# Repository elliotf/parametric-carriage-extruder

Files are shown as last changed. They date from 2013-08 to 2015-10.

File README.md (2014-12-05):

A perimetric modular carriage + extruder system.

Heavily inspired by http://www.thingiverse.com/thing:321523

Currently designing for direct-driving 3mm filament.  Note that you'll likely want to use a 0.9 degree (400-step) motor to have sufficient steps/mm and/or 1/32 microstepping.

The design is parametric and should be able to be changed to 1.75mm filament if you so desire -- see 'filament_diam' variable.

The idea is that the extruder bolts to the face of the motor, then the motor is clamped to the x carriage in some way, assuming an XZ/Y printer.  Currently designing for a Graber/Prusa i3 vertical carriage, but a wades-style two-hole mounting system shouldn't be hard at all.

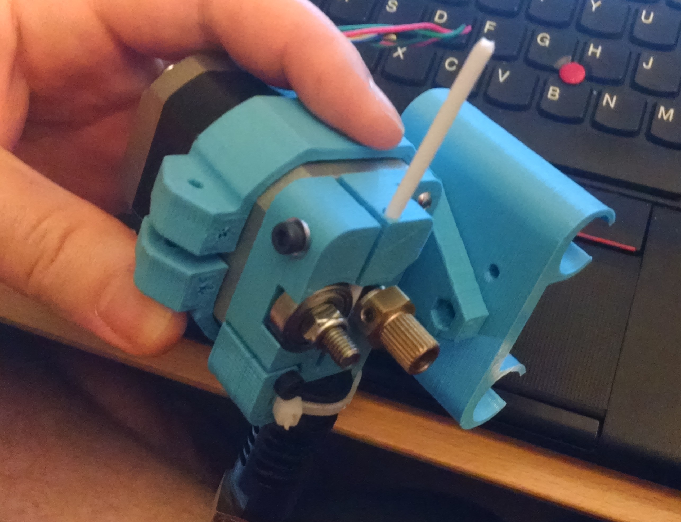
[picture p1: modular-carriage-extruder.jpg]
preview


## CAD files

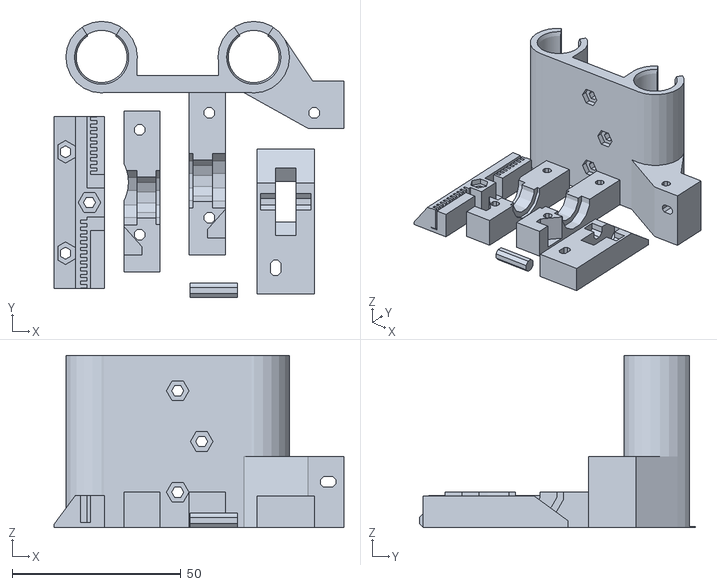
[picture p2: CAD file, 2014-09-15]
output/main_plate.stl
85.8 x 81.7 x 51.0

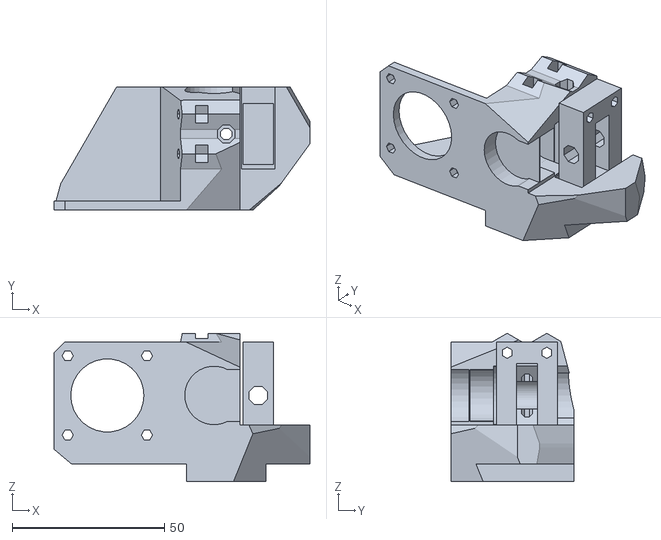
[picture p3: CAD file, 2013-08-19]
stl/assembly.stl
84.0 x 40.5 x 48.7

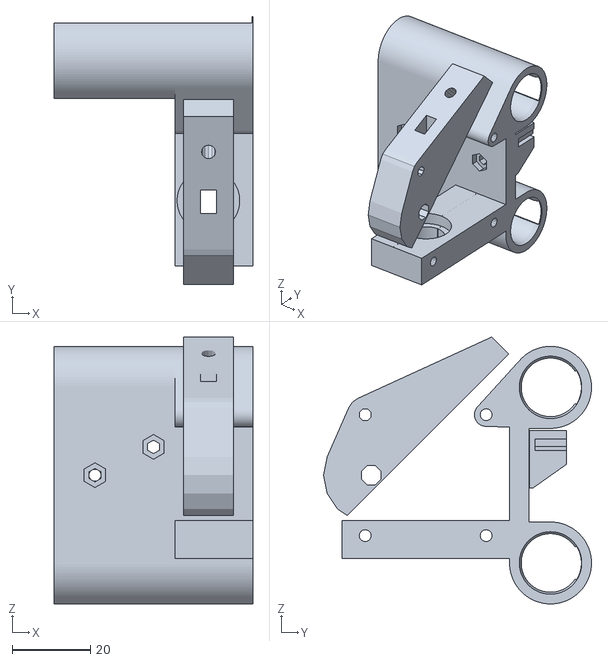
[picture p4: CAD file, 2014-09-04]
output/assembly.stl
51.0 x 68.7 x 68.4

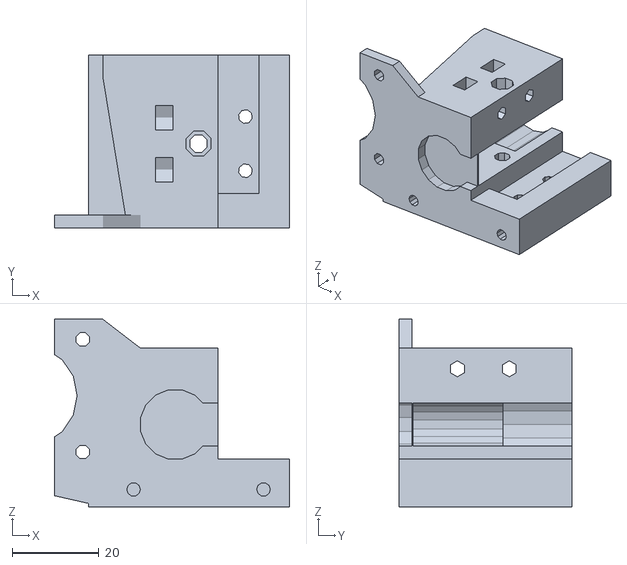
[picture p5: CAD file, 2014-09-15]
main.stl
54.3 x 40.0 x 43.3

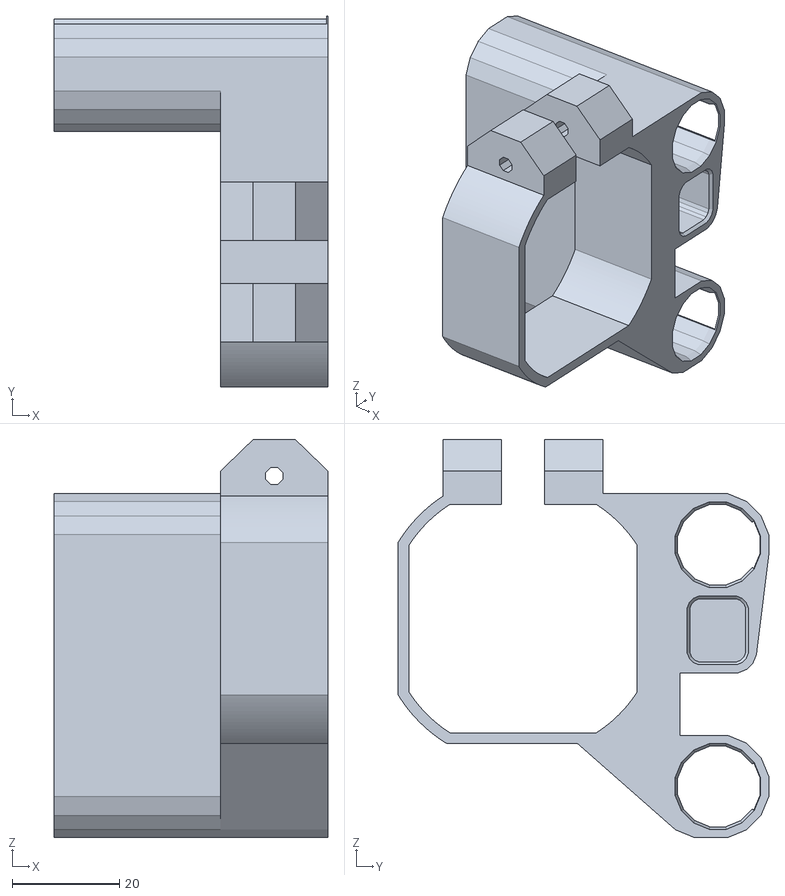
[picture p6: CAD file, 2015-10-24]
carriage-only.stl
51.0 x 69.0 x 74.1

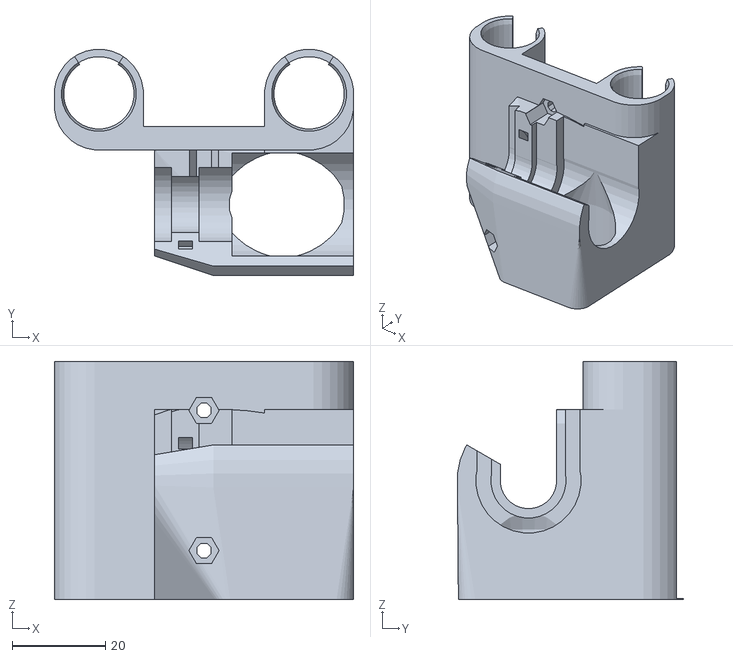
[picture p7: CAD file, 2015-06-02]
e3d-carriage-only.stl
64.0 x 48.4 x 51.0

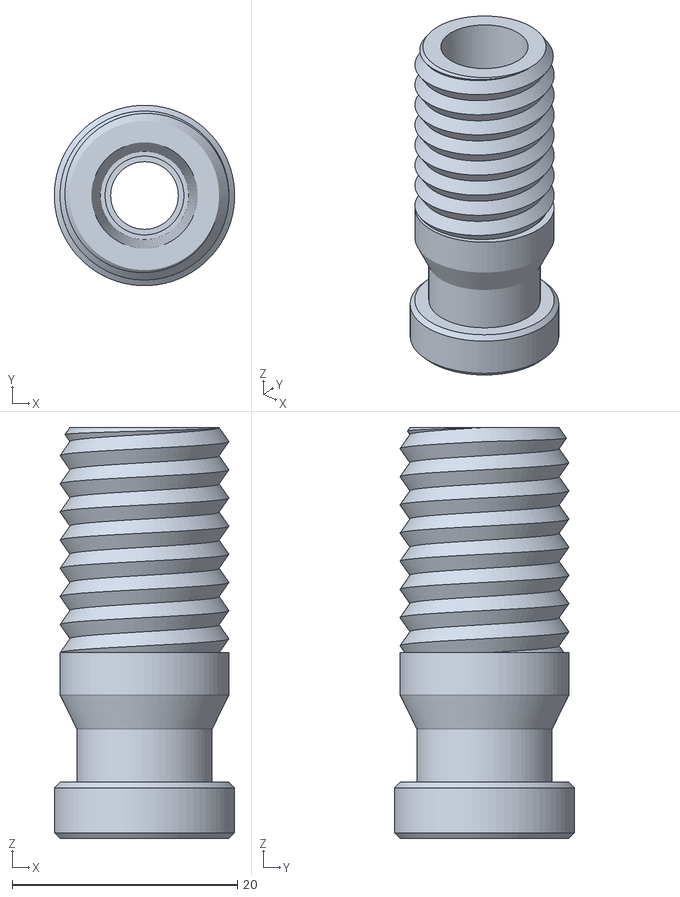
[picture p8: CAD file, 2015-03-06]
bowden-jhead-adapter.stl
16.0 x 16.0 x 36.5

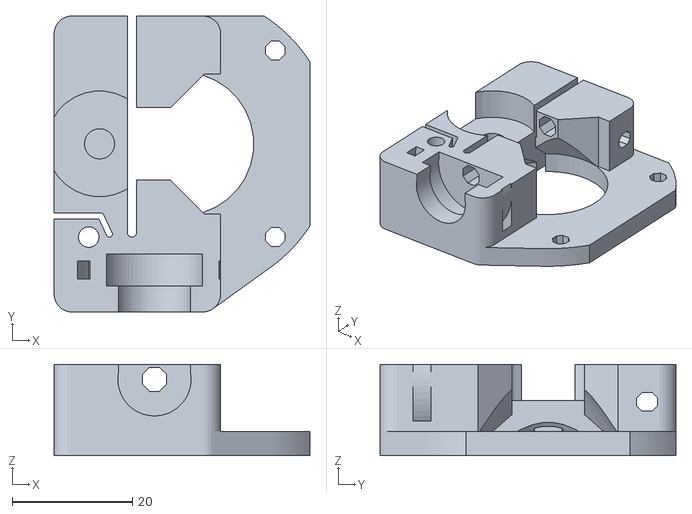
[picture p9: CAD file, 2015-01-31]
direct-drive-only.stl
42.5 x 49.2 x 15.2

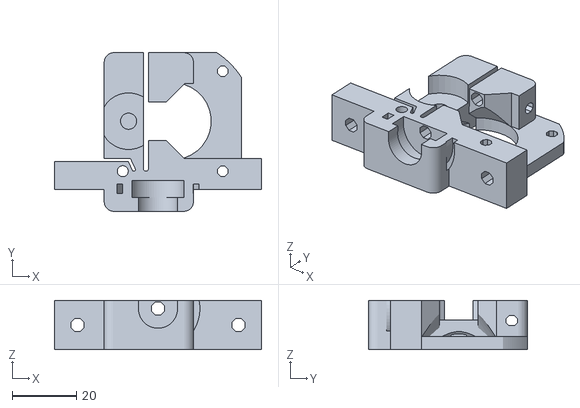
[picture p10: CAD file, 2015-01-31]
direct-drive-only-groove_mount_flush_with_motor-jhead.stl
64.2 x 49.2 x 15.2

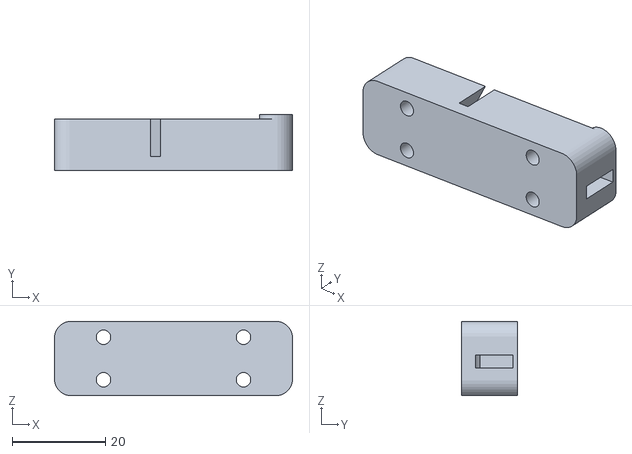
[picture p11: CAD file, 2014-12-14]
belt_clamp.stl
51.0 x 12.0 x 15.9

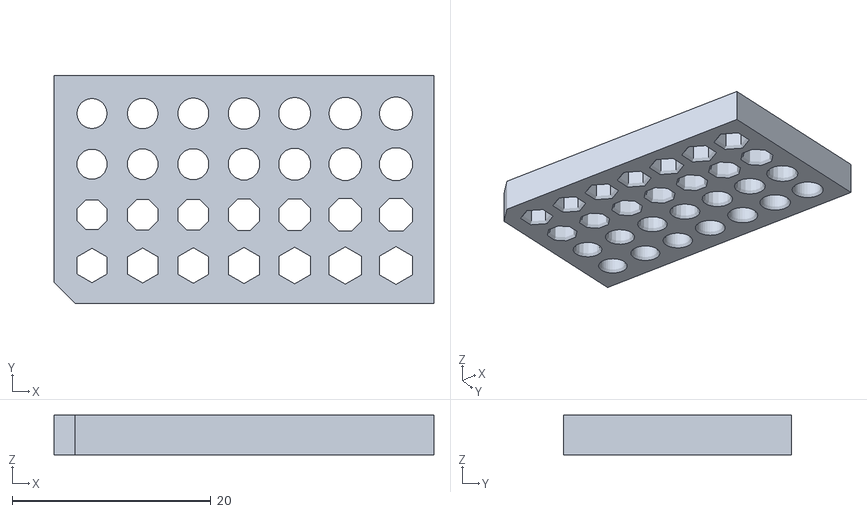
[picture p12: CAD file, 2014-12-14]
calibration.stl
38.2 x 22.9 x 4.00

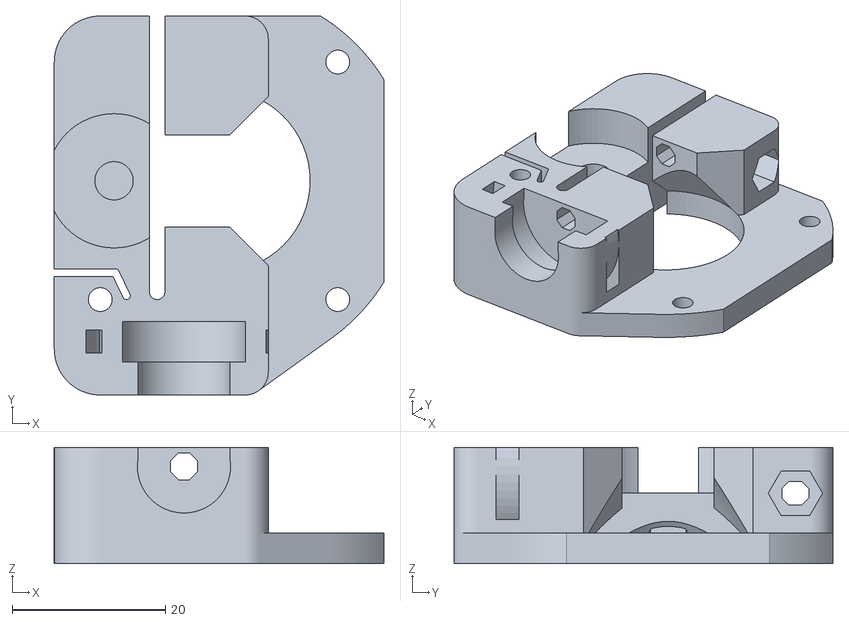
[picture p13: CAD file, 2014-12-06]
direct-drive-only-jhead_mk5-3mm.stl
43.0 x 49.5 x 15.2

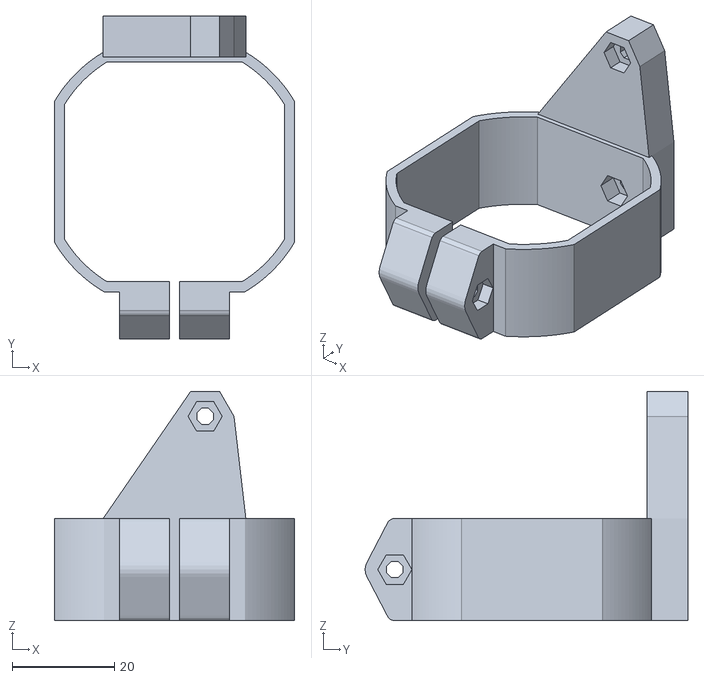
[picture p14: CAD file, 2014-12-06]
motor_clamp.stl
47.0 x 63.2 x 44.9

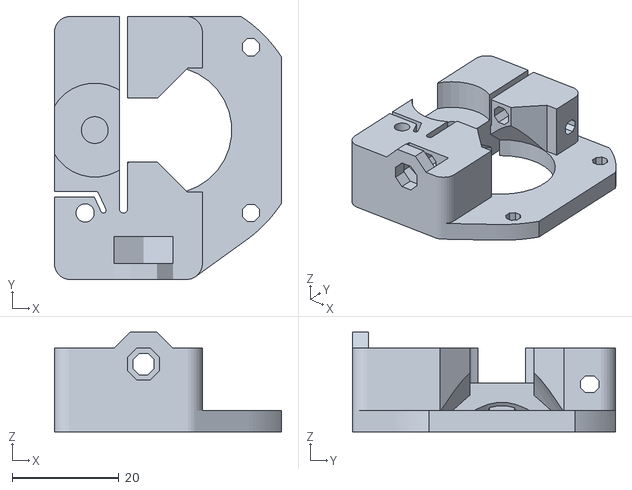
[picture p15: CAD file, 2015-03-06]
direct-drive-only-bowden-nut.stl
42.5 x 49.2 x 18.7

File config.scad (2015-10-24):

motor_pulley_tooth_pitch = 2; // GT2 belt
motor_pulley_tooth_count = 16;

// All hail whosawhatsis
pi  = 3.14159265359;

resolution = 32;
rotation   = 180/resolution;

motor_clamp_mount_width     = 20;
motor_clamp_mount_thickness = 8;

// make coordinates more communicative
left  = -1;
center = 0;
right = 1;
front = -1;
rear  = 1;
top = 1;
bottom  = -1;

// address vector positions by their name
x = 0;
y = 1;
z = 2;

// Screws, nuts
m3_diam          = 3.1;
m3_diam_vertical = 3.2; // after printer calibration check
m3_nut_diam  = 5.6;
m3_nut_thickness  = 2.5;
m3_nut_height  = m3_nut_thickness;
m3_socket_head_diam = 6;
m3_socket_head_height = 3;

m5_diam = 5;
m5_nut_diam = 8;
m5_nut_thickness = 4;
m5_nut_height = m5_nut_thickness;

// Motors
nema17_side = 42.5;
nema17_diam = 50.5;
nema17_len = 36; // "half-length" nema 17
nema17_len = 48;
nema17_hole_spacing = 31;
nema17_screw_diam = m3_diam;
nema17_shaft_diam = 5;
nema17_shaft_len = 22;
nema17_short_shaft_len = 0;
nema17_shoulder_height = 2;
nema17_shoulder_diam = nema17_hole_spacing*.75;

nema14_side = 35.3;
nema14_len = 36;
nema14_hole_spacing = 26;
nema14_screw_diam = m3_diam;
nema14_shaft_diam = 5;
nema14_shaft_len = 20;
nema14_short_shaft_len = 20;
nema14_shoulder_height = 2;
nema14_shoulder_diam = 22;

motor_side = nema17_side;
motor_diam = nema17_diam;
motor_len = nema17_len;
motor_hole_spacing = nema17_hole_spacing;
motor_shaft_diam = nema17_shaft_diam;
motor_shaft_len = nema17_shaft_len;
motor_short_shaft_len = nema17_short_shaft_len;
motor_shoulder_height = nema17_shoulder_height;
motor_shoulder_diam = nema17_shoulder_diam;

/*
motor_side = nema14_side;
motor_len = nema14_len;
motor_hole_spacing = nema14_hole_spacing;
motor_shaft_diam = nema14_shaft_diam;
motor_shaft_len = nema14_shaft_len;
motor_short_shaft_len = nema14_short_shaft_len;
motor_shoulder_height = nema14_shoulder_height;
motor_shoulder_diam = nema14_shoulder_diam;
*/

motor_screw_head_diam = 6;

// Misc settings
extrusion_width = 0.5;
extrusion_height = 0.3;
min_material_thickness = extrusion_width*2;
spacer = 1;

// bearing size

// 4-40
idler_screw_diam = 3.2;
idler_nut_diam = 6.8;
idler_nut_thickness = 2.5;

// m3

// 608
idler_bearing_height = 7;
idler_bearing_outer  = 22;
idler_bearing_inner  = 8;
idler_nut_diam       = 13;

//626
idler_bearing_height = 6;
idler_bearing_outer  = 19;
idler_bearing_inner  = 6;
idler_nut_diam       = 10;

//625
idler_bearing_height      = 5;
idler_bearing_outer       = 16;
idler_bearing_inner       = 5;
idler_screw_diam          = m5_diam;
idler_nut_diam            = m5_nut_diam;
idler_nut_thickness       = m5_nut_thickness;

/*
//624
idler_bearing_height = 5;
idler_bearing_outer  = 13;
idler_bearing_inner  = 4;

//623
idler_bearing_height      = 4;
idler_bearing_outer       = 10;
idler_bearing_inner       = 3;
idler_screw_diam          = m3_diam;
idler_nut_diam      = m3_nut_diam;
idler_nut_thickness = 2.5;
*/

filament_diam = 3;
filament_compressed_diam = filament_diam * 0.75;
filament_opening_diam = filament_diam + 0.5;

hobbed_pulley_height  = 11;
hobbed_pulley_len     = hobbed_pulley_height;
hobbed_effective_diam = 6.9;
hobbed_pulley_diam    = 9;
hob_dist_from_end     = 3.25;
hob_width             = 3.5;
hob_depth             = hobbed_pulley_diam/2-hobbed_effective_diam/2;

hotend_length      = 63;
hotend_diam        = 16;
hotend_groove_diam = 12;
hotend_clearance   = 0.15;

// e3d v6 direct
hotend_height_above_groove = 3.7;
hotend_groove_height = 6;

// jhead
hotend_height_above_groove = 5;
hotend_groove_height = 4.6;
/*
*/

hotend_clamped_height = hotend_height_above_groove + hotend_groove_height;

wall_thickness = extrusion_width*4;

motor_pulley_circumference = motor_pulley_tooth_pitch * motor_pulley_tooth_count;
motor_pulley_diameter      = motor_pulley_circumference / pi;
belt_thickness = .95;
belt_tooth_height   = 1.5;
belt_tooth_distance = 2;
belt_tooth_ratio    = 0.5;
belt_width = 6;
belt_opening_width = 8;

x_rod_spacing   = 45;
pulley_offset_z = -1.75;

// lm8uu
bearing_len = 25;
bearing_diam = 15;

carriage_screw_spacing = 30;

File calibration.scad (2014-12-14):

include <util.scad>
include <config.scad>
use <motor_clamp.scad>

module m3_hole_calibration() {
  offset = wall_thickness+m3_diam;
  diams=[m3_diam];
  steps=[-2,-1,0,1,2,3,4];
  resolutions=[8,16,32];

  max_res_index  = 3;
  max_diam_index = 6;

  size_x = offset*(max_diam_index+1.5);
  size_y = offset*(max_res_index+1.5);
  size_z = 4;

  module body() {
    cube([size_x,size_y,size_z]);
  }

  module holes() {
    offset = wall_thickness+m3_diam;
    diams=[m3_diam];
    steps=[-2,-1,0,1,2,3,4];
    resolutions=[6,8,16,32];
    for(res=[0:max_res_index]) {
      for(try=[0:max_diam_index]) {
        translate([offset*(try+.75),offset*(res+.75),0]) {
          rotate([0,0,180/resolutions[res]]) {
            hole(m3_diam+(.05*steps[try]),10,resolutions[res]);

            hull() {
              translate([0,0,-.1]) {
                hole(m3_diam+(.05*steps[try])+.6,.1,resolutions[res]);
                hole(m3_diam+(.05*steps[try]),.9,resolutions[res]);
              }
            }
          }
          echo("DIAM: ", m3_diam+(.05*steps[try]));
        }
      }
    }
  }

  difference() {
    body();
    holes();
  }
}

m3_hole_calibration();

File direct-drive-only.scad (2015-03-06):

include <util.scad>
include <config.scad>

idler_shaft_support   = 4;

filament_opening = filament_diam + 1;

plate_thickness = motor_shoulder_height;
plate_thickness = 4;
filament_pos_x  = (hobbed_effective_diam/2+filament_compressed_diam/2)*left;
filament_pos_y  = 0;
idler_nut_pos_z = motor_shoulder_height + extrusion_height + idler_nut_thickness/2;
idler_pos_x     = filament_pos_x - (filament_compressed_diam/2+idler_bearing_outer/2);
idler_pos_z     = idler_nut_pos_z + idler_nut_thickness/2 + idler_shaft_support + idler_bearing_height/2;
filament_pos_z  = idler_pos_z;

hinge_space_width = 1.5;
hinge_space_pos_x = filament_pos_x - filament_opening/2 - extrusion_width*2 - hinge_space_width/2;
hinge_pos_y       = - motor_hole_spacing/2;

hotend_pos_y      = -motor_hole_spacing/2-motor_screw_head_diam/2;

idler_screw_pos_y = motor_side/2-wall_thickness-m3_nut_diam/2;
idler_screw_pos_z = filament_pos_z - filament_opening/2 - extrusion_height - m3_diam/2;
idler_washer_thickness = 1;

echo("Idler screw length at least ", idler_shaft_support*2 + 1 + idler_bearing_height + 3);

groove_mount_wings = true;
groove_mount_wings = false;
groove_mount_wings_hole_spacing = 50;
groove_mount_wings_hole_diam    = 4.1;
groove_mount_wings_nut_diam     = 4.1;
groove_mount_wings_thickness    = 8;
groove_mount_wings_thickness    = (motor_side-motor_shoulder_diam)/2;

bowden_nut_diam      = 11;
bowden_nut_thickness = 5;
bowden_tubing_diam   = 6; // 0.25inch threaded diam

OUTPUT_NONE         = 0;
OUTPUT_GROOVE_MOUNT = 1;
OUTPUT_BOWDEN       = 2;
output              = OUTPUT_NONE;
output              = OUTPUT_BOWDEN;
output              = OUTPUT_GROOVE_MOUNT;

module direct_drive() {
  rounded_radius = motor_side/2 - motor_hole_spacing/2;
  block_height = idler_pos_z + idler_bearing_height/2 + idler_washer_thickness + idler_shaft_support;
  block_height = idler_pos_z + idler_bearing_height/2 + .5;
  block_height = filament_pos_z + filament_opening/2 + 1;

  hotend_rounded_corner_radius = 3;
  hotend_rounded_corner_pos_x  = filament_pos_x+hotend_diam/2;
  hotend_rounded_corner_pos_y  = hotend_pos_y-hotend_clamped_height+hotend_rounded_corner_radius+hotend_clearance;
  module body() {
    hull() {
      translate([0,0,plate_thickness/2]) {
        rounded_square(motor_side,motor_diam,plate_thickness);
      }
      if (!groove_mount_wings) {
        translate([hotend_rounded_corner_pos_x,hotend_rounded_corner_pos_y,plate_thickness/2]) {
          hole(hotend_rounded_corner_radius*2,plate_thickness,resolution);
        }
      }
    }

    // main block
    hull() {
      for(y=[motor_side/2-hotend_rounded_corner_radius,hotend_rounded_corner_pos_y]) {
        for (x=[(motor_side/2-hotend_rounded_corner_radius)*left,hotend_rounded_corner_pos_x]) {
          translate([x,y,block_height/2]) {
            hole(hotend_rounded_corner_radius*2,block_height,resolution);
          }
        }
      }
    }

    if (groove_mount_wings) {
      hull() {
        for(side=[left,right]) {
          // groove mount is flush with bottom of extruder, but motor is cantilevered
          //for(y=[hotend_rounded_corner_pos_y-hotend_rounded_corner_radius+groove_mount_thickness/2]) {
          // groove mount is flush with face of motor, so no overhang, but extruder extends into carriage hole
          for(y=[-motor_side/2+groove_mount_wings_thickness/2]) {
            translate([filament_pos_x+(groove_mount_wings_hole_spacing/2+groove_mount_wings_nut_diam)*side,y,block_height/2]) {
              cube([hotend_rounded_corner_radius*2,groove_mount_wings_thickness,block_height],center=true);
            }
          }
        }
      }
    }

    if (output == OUTPUT_BOWDEN) {
      translate([filament_pos_x,hotend_rounded_corner_pos_y-hotend_rounded_corner_radius/2,filament_pos_z]) {
        rotate([90,0,0]) {
          hole(bowden_tubing_diam+6,hotend_rounded_corner_radius,8);
        }
      }
    }
  }

  module holes() {
    tensioner_wiggle = .4;
    translate([0,idler_screw_pos_y,idler_screw_pos_z]) {
      for(side=[front,rear]) {
        // tensioner screw
        translate([0,tensioner_wiggle/2*side,0]) {
          rotate([0,90,0]) {
            hole(m3_diam,motor_side*2,8);
          }
        }
        // tensioner captive nut
        translate([-motor_side/2,tensioner_wiggle/2*side,0]) {
          rotate([0,90,0]) {
            hole(m3_nut_diam,10,6);
          }
        }
      }
    }

    if (groove_mount_wings) {
      for(side=[left,right]) {
        translate([filament_pos_x+groove_mount_wings_hole_spacing/2*side,-motor_side/2,block_height/2]) {
          rotate([90,0,0]) {
            hole(4.1,30,8);
          }
        }
      }
    }

    // motor mount holes
    for(side=[top,bottom]) {
      translate([motor_hole_spacing/2,motor_hole_spacing/2*side,0]) {
        hole(m3_diam_vertical,motor_len,8);
      }
    }
    translate([-motor_hole_spacing/2,-motor_hole_spacing/2,0]) {
      hole(m3_diam_vertical+.2,motor_len,resolution);
    }

    // motor shoulder + slack
    mount_shoulder_width = motor_shoulder_diam/2+abs(hinge_space_pos_x)+1;
    intersection() {
      hull() {
        hole(motor_shoulder_diam+0.5,plate_thickness*2+0.05,resolution);
        hole(2,(plate_thickness+motor_shoulder_diam/2+2)*2,resolution);
      }
      translate([motor_shoulder_diam/2-mount_shoulder_width/2+1,0,0]) {
        cube([mount_shoulder_width,motor_shoulder_diam+1,motor_len],center=true);
      }
    }

    // idler arm motor shoulder clearance
    intersection() {
      translate([-0.5,0,0]) {
        hull() {
          hole(motor_shoulder_diam+0.5,motor_shoulder_height*2,resolution);
          hole(2,(motor_shoulder_height+motor_shoulder_diam/2)*2,resolution);
        }
      }
      translate([hinge_space_pos_x-motor_side/2,0,0]) {
        cube([motor_side+0.05,motor_side+0.05,motor_len],center=true);
      }
    }

    // pulley clearance
    hole(hobbed_pulley_diam+2,motor_len,resolution);
    pulley_clearance = hobbed_pulley_diam+3;
    hull() {
      translate([hinge_space_pos_x,0,0]) {
        cube([1,pulley_clearance,motor_len],center=true);
      }

      translate([rounded_radius,0,0]) {
        cube([1,pulley_clearance,motor_len],center=true);
      }
    }
    // hobbed pulley access
    translate([motor_side*.2,0,plate_thickness+motor_len/2]) {
      hole(motor_shoulder_diam,motor_len,8);
    }

    // hinge space between idler and hobbed pulley
    hull() {
      translate([hinge_space_pos_x,hinge_pos_y+hinge_space_width/2,0]) {
        hole(hinge_space_width,motor_len,resolution);

        translate([0,motor_side,0]) {
          cube([hinge_space_width,1,motor_len],center=true);
        }
      }
    }

    // hinge space between idler and motor mount screw
    translate([hinge_space_pos_x-hinge_space_width/2-3,hinge_pos_y+0.5,0]) {
      hull() {
        hole(1,motor_len,resolution);

        translate([-(motor_screw_head_diam/2-m3_diam_vertical/2),motor_screw_head_diam/2,0]) {
          hole(1,motor_len,resolution);
        }
      }

      hull() {
        translate([-(motor_screw_head_diam/2-m3_diam_vertical/2),motor_screw_head_diam/2,0]) {
          hole(1,motor_len,resolution);

          translate([-motor_side,0,0]) {
            cube([hinge_space_width,1,motor_len],center=true);
          }
        }
      }
    }

    translate([idler_pos_x,0,0]) {
      // idler shaft
      hole(idler_bearing_inner,motor_len,resolution);

      // idler bearing
      translate([0,0,idler_pos_z]) {
        hole(idler_bearing_outer+1.5,idler_bearing_height+idler_washer_thickness*2,resolution);
      }

      // captive idler nut/bolt
      hull() {
        translate([0,0,idler_nut_pos_z]) {
          hole(idler_nut_diam,idler_nut_thickness,6);

          translate([0,0,-motor_len/2]) {
            hole(idler_nut_diam,idler_nut_thickness,6);
          }
        }
      }
    }

    bevel_dist = extrusion_height*3;
    translate([idler_pos_x,0,0]) {
      // created a bevel in case the first few layers are melted into a flange
      hull() {
        hole(idler_nut_diam,motor_shoulder_height,6);
        hole(idler_nut_diam+bevel_dist*2,0.05,36);
      }
    }

    // filament path
    translate([filament_pos_x,0,filament_pos_z]) {
      rotate([90,0,0]) {
        hole(filament_opening,70,8);
      }
    }

    // hotend void
    hotend_res = resolution*2;
    above_height = hotend_height_above_groove+hotend_clearance*2;
    if (output == OUTPUT_GROOVE_MOUNT) {
      translate([filament_pos_x,hotend_pos_y,filament_pos_z]) {
        rotate([-90,0,0]) {
          translate([0,0,-hotend_clamped_height]) {
            hole(hotend_groove_diam+hotend_clearance,hotend_clamped_height*2,hotend_res);
            translate([0,-hotend_diam/2,0]) {
              cube([hotend_groove_diam,hotend_diam,hotend_clamped_height*2],center=true);
            }
          }
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

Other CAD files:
direct-drive-only-groove_mount_flush_with_extruder-jhead.stl
for-geared-stepper.scad
assembly.scad
bowden-jhead-adapter.scad
carriage-only.scad
gears.scad
hotends.scad
inc/nema.scad
inc/parametric_involute_gear_v5.0.scad
inc/spur_generator.scad
main.scad
motor_clamp.scad
output/main_plate.scad
polyScrewThread.scad
polyScrewThread_r1.scad
positions.scad
util.scad

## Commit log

2013-08-19 Implement a groove mount to allow lower carriage mount holes
    [assembly.scad]
2013-08-19 STL snapshot of progress
    [assembly.stl]
2013-08-23 Commit work on groove mount, going back to non-groove mount
    [assembly.scad]
2013-11-04 Mounting a groove mount does not require a plate
    [base.scad, gears.scad, main.scad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]
2014-06-10 First pass at using kossel hotend mount plate
    [base.scad, main.scad, positions.scad]
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2014-06-30 Attempt to better represent filament/hobbed whatnot
    [base.scad, main.scad, positions.scad]
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2014-06-30 Allow more tolerance of drop on filament opening
    [base.scad]
2014-06-30 About to start on idler
    [base.scad, main.scad, positions.scad]
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2014-07-02 Make file structure simpler
    [base.scad, config.scad]
2014-07-02 More WIP
    Commit messages are hard for openscad.
    [config.scad, main.scad, positions.scad]
2014-07-02 Idler has something to brace against
    [config.scad, main.scad, positions.scad]
2014-07-02 Idler is more real
    [config.scad, main.scad]
2014-07-02 Printed groove mount hotend retainer
    [config.scad, main.scad]
2014-07-02 Maybe easier to print holes
    [main.scad]
2014-07-02 Easier to work on while mounted
    * Can unscrew shaft while mounted
    * Easier to insert carriage-side bearing
    [main.scad]
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2014-07-02 Prevent bearing from rubbing against plastic
    [config.scad, main.scad, positions.scad]
2014-07-02 Loosen tolerances
    [config.scad]
2014-07-03 Carriage hole bracing WIP
    [config.scad, main.scad, positions.scad]
2014-07-03 New extruder print plate
    [main_plate.scad]
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2014-08-31 Progress on direct-drive carriagestruder for i3
    [config.scad, main.scad, main_plate.scad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]
2014-08-31 Changes to improve ease of printing
    [main.scad, main_plate.scad]
2014-08-31 Rendered plate of direct-drive carriagestruder
    [main_plate.stl]
2014-09-01 Avoid mid-air printing
    [main_plate.scad]
2014-09-01 Clean up around hobbed/filament/idler contact area
    [main.scad, positions.scad]
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2014-09-01 Before messing with idler arm
    [config.scad, main.scad]
2014-09-04 First pass at direct-drive extruder
    [config.scad, main.scad, main_plate.scad]
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2014-09-11 Working on tensioner/idler arm
    [config.scad, main.scad, positions.scad]
2014-09-11 Avoid things being printed as one
    [main_plate.scad]
2014-09-14 Try #3 of a tensioner/idler arm
    [config.scad, main.scad, positions.scad]
2014-09-14 Tensioner screw to compress idler against filament
    [config.scad, main.scad, main_plate.scad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]
2014-09-14 Wiggle room for idler screw deflection
    [main.scad, positions.scad]
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2014-09-15 Printed, nothing obvious to change
    [main.stl]
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2014-11-30 Direct-drive extruder rather than carriagestruder
    Heavily inspired by http://www.thingiverse.com/thing:321523
    [config.scad, direct-drive-only.scad]
2014-11-30 More tolerant of poorly calibrated first layer
    [direct-drive-only.scad]
2014-11-30 Main plate is sturdier, easier to print in ABS
    [direct-drive-only.scad]
2014-11-30 Flat is no longer needed
    [direct-drive-only.scad]
2014-11-30 More clearance for pulley set screw
    [direct-drive-only.scad]
2014-11-30 Use a metal washer instead of printed spacer
    The printed spacer seems to compress and bind
    [direct-drive-only.scad]
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2014-12-01 Push more things down
    [config.scad, direct-drive-only.scad, util.scad]
2014-12-01 Clean up, make use of reusable code
    [config.scad, direct-drive-only.scad, positions.scad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]
2014-12-01 WIP of plain (non-carriagestruder) x-carriage
    [carriage-only.scad]
2014-12-05 Source of print on 2014/12/03
    [carriage-only.scad]
2014-12-05 Carriage render printed 2014/12/03
    [carriage-only.stl]
2014-12-05 First pass at motor mount clamp
    [motor_clamp.scad]
2014-12-05 Motor mount clamp printed 2014/12/03
    [motor_clamp.stl]
2014-12-05 Direct-drive for MK5 j-head printed 2014/12/01
    MK5 hotends.com j-head, 3mm filament, 625zz idler, mk8 hobbed pulley
    [direct-drive-only.stl]
2014-12-06 Make motor clamp more flexible
    [carriage-only.scad, motor_clamp.scad, util.scad]
2014-12-06 Match motor profile more
    [direct-drive-only.scad]
2014-12-06 Integrated clamp + carriage
    [carriage-only.scad, config.scad, motor_clamp.scad]
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2014-12-07 More clearance for motor wires
    [motor_clamp.scad]
2014-12-07 Strengthened unified motor clamp carriage
    [carriage-only.scad, config.scad, motor_clamp.scad]
2014-12-14 Prepare to have idler toward carriage
    So the hobbed pulley is open to the printer operator
    [config.scad, direct-drive-only.scad]
2014-12-14 Printing at the moment.
    [direct-drive-only.stl]
2014-12-14 New x carriage belt clamp with zip tie tensioner
    [carriage-only.scad, config.scad]
2014-12-14 Calibration piece for sizing 3mm holes
    [calibration.scad]
2014-12-14 Calibration piece as printed on 2014/12/13
    [calibration.stl]
2014-12-14 Belt clamp as printed on 2014/12/13
    [belt_clamp.stl]
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2014-12-17 Adjust sizing for NEMA17 motor
    Less parametric, but the nema14 sizes are just made up, anyway
    [config.scad, motor_clamp.scad, util.scad]
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2014-12-24 Call rounded_square with new signature
    Ah, coding without tests...
    [direct-drive-only.scad]
2014-12-24 Make the clamp stronger to avoid delamination
    I had partial clamp delamination under heavy clamping forces when
    previously printed. Using more material results in a much stronger
    clamp.
    [motor_clamp.scad]
2014-12-24 e3d v6 version of the direct drive extruder
    [config.scad]
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2014-12-24 STL rendering of e3d v6 direct drive extruder
    [direct-drive-only.stl]
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2015-01-31 Increase filament hole diam, avoid binding
    A rendering with a larger diameter filament hole to help avoid binding.
    [direct-drive-only.stl]
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2015-03-06 An attempt to have a minimal bowden
    Using a pair .25 inch 20-thread-per-inch nuts, putting a thread on the
    PTFE tubing, but the nuts seem to come loose as the tube moves back and
    forth. :\
    [direct-drive-only.scad]
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2015-03-06 An attempt to create a jhead bowden adapter
    [bowden-jhead-adapter.stl]
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2015-05-11 Giving up, buying a geared stepper.
    Here's an extruder body for it.
    [for-geared-stepper.scad]
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2015-05-29 Carriage that clamps an e3d v6 for bowden
    [carriage-only.scad, hotends.scad]
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2015-05-29 Avoid degenerate polygons, correct orientation
    [carriage-only.scad]
2015-05-29 Rendering with correct print orientation
    [e3d-carriage-only.stl]
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
